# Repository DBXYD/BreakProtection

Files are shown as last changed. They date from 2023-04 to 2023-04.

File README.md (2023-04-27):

# 3A_BREAK

## Components
* MOSFET de puissance, Canal N, 100 V, 31 A, 0.031 ohm, TO-263 (D2PAK), Montage en surface :  
https://fr.farnell.com/nexperia/buk9637-100e-118/mosfet-n-ch-100v-31a-d2pak/dp/2254193

* Régulateur à découpage Buck (Step Down), Fixe, Entrée 7.5V à 76V, Sortie 5V 500mA 125 kHz NSOIC-8 :  
https://fr.farnell.com/maxim-integrated-products/max5033busa/convertisseur-dc-dc-buck-125khz/dp/2513947

* Redresseur Schottky, 100 V, 2 A, Une, DO-220AA, 2 Broche(s), 800 mV :  
https://fr.farnell.com/vishay/ss2ph10-m3-84a/diode-rectifier-schottky-2a-100v/dp/1812489

* WE-PDA SMT Shielded Power Inductor EXTENDED - 784771221 - 220uH 0.99A :  
https://www.we-online.com/catalog/en/WE-PDA?sq=784771221#784771221

* Carte de développement, MCU Nucleo-G431KB, STM32G431KBT6U, Arduino Nano V3 :   
https://fr.farnell.com/stmicroelectronics/nucleo-g431kb/carte-de-dev-32-bits-arm-cortex/dp/3132398

* Bornier fil-à-carte, 5.08 mm, 2 Voies, 26 AWG, 12 AWG, 4 mm², Par vis :  
https://fr.farnell.com/multicomp/mc000034/bornier-ci-noir-5-08mm-vis-02/dp/2008004

* CI Driver de MOSFET, Low Side, Alimentation 4.5V à 16V, 2A Out, 35ns Retard, SOIC-8 :  
https://fr.farnell.com/microchip/tc1412neoa/driver-mosfet-2a-non-inv-8soic/dp/1834898

* Redresseur Schottky, 60 V, 15 A, Une, TO-263AB, 3 Broche(s), 620 mV :  
https://fr.farnell.com/vishay/vs-15tq060s-m3/diode-schottky-simple-60v-to263ab/dp/2909608

* Codeur rotatif, Mécanique, Incrémental, 15 PPR, 30 crans, Verticale, Avec commutateur push :  
https://fr.farnell.com/wurth-elektronik/482016514001/codeur-rotatif-mecanique-incremental/dp/3806131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

* Afficheur LCD, Grove, LCD RGB 16X2 rétroéclairage, Interface I2C :  
https://fr.farnell.com/seeed-studio/104030001/grove-cran-lcd-rvb-r-tro-clair/dp/3932101

## Tools

* Calcul isolement :  
https://www.smps.us/pcbtracespacing.html

## Export Gerber 

CAM Processor
CAMOutputs

### LPKF
* Switch on LPKF
* Open LPKF CircuitPro PM 2.7 software
* Wait few minutes
* Choose Template DoubleSided_Galvanic_THP
* Check Machining -> Connect... (if not) -> S62
* Calibration Key is incorrect -> ok
* Import Data from a non-native format 
* -> Import all gerbers and drillfiles
* Generate isolation and contour -> 35um
* Process -> 4/4

### Photo-ploter
* Gerb2BMP : 
* Import Master Gerber
* Copper_Top // Copper_botton
* Export Gerber to bitmap file (2032 dpi)

* Filmstar : Generate and run on photoploter
* CUIVRE : NEGATIVE !!!
*

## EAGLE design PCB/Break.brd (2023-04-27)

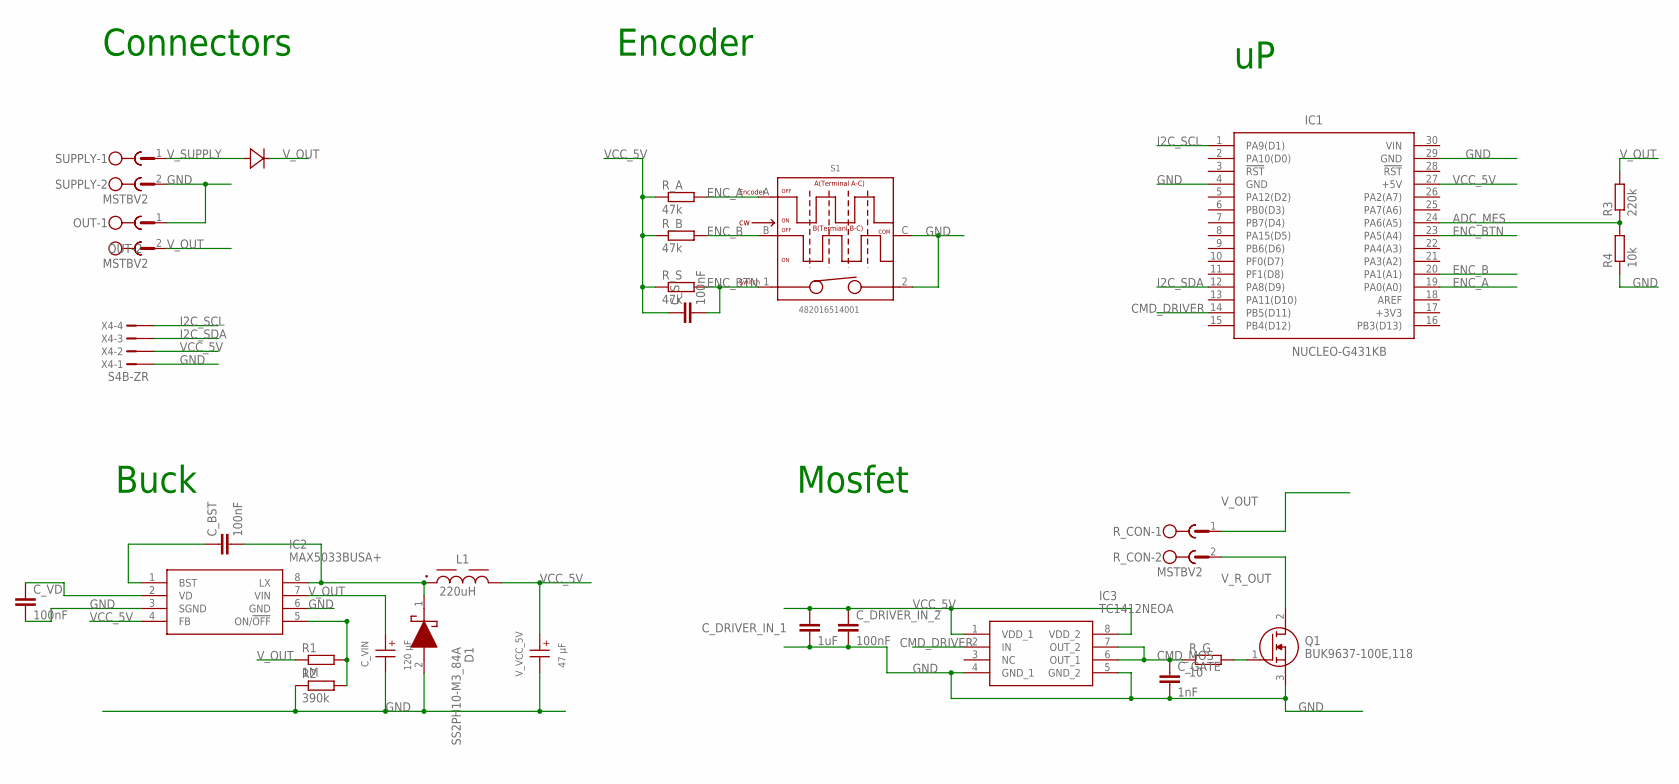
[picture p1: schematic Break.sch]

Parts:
C_BST: 100nF; C0603
C_DRIVER_IN_1: 1uF; C0603
C_DRIVER_IN_2: 100nF; C0603
C_GATE: 1nF; C0603
C_S: 100nF; C0603
C_VD: 100nF; C0603
C_VIN: 120 µF; WCAP-ATG8_18X41X7.5(DXL)
D1: SS2PH10-M3_84A; DO-220AA
IC1: NUCLEO-G431KB; DIPS1524W66P254L5029H1500Q30N
IC2: MAX5033BUSA+; SOIC127P600X175-8N
IC3: TC1412NEOA; SOIC127P600X175-8N
L1: 220uH; WE-PDA_1260
OUT: MSTBV2
Q1: BUK9637-100E,118; PSMN4R480BS118
R1: 1M; R0603
R2: 390k; R0603
R3: 220k; R0603
R4: 10k; R0603
R_A: 47k; R0603
R_B: 47k; R0603
R_CON: MSTBV2
R_G: 10; R1206
R_S: 47k; R0603
S1: 482016514001; WS-ENTV_4820XX514001
SUPPLY: MSTBV2
U$1: VS-15TG060S-M3; SMD-220
V_VCC_5V: 47 µF; WCAP-ASLL_6.3X5.5(DXL)
X4: S4B-ZR

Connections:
ADC_MES: IC1.24 (PA6(A5)), R3.1, R4.2
CMD_DRIVER: IC1.14 (PB5(D11)), IC3.2 (IN)
CMD_MOS: C_GATE.1, IC3.6 (OUT_1), IC3.7 (OUT_2), R_G.1
ENC_A: IC1.19 (PA0(A0)), R_A.2, S1.A
ENC_B: IC1.20 (PA1(A1)), R_B.2, S1.B
ENC_BTN: C_S.2, IC1.23 (PA5(A4)), R_S.2, S1.1
GND: C_DRIVER_IN_1.2, C_DRIVER_IN_2.2, C_GATE.2, C_VD.2, C_VIN.2 (-), D1.2 (A), IC1.4 (GND), IC1.29 (GND), IC2.3 (SGND), IC2.6 (GND), IC3.4 (GND_1), IC3.5 (GND_2), OUT.1, Q1.3 (S), R2.1, R4.1, S1.2, S1.C (COM), SUPPLY.2, V_VCC_5V.2 (-), X4.1
I2C_SCL: IC1.1 (PA9(D1)), X4.4
I2C_SDA: IC1.12 (PA8(D9)), X4.3
unnamed: Q1.1 (G), R_G.2
unnamed: C_BST.2, D1.1 (K), IC2.8 (LX), L1.1
unnamed: C_VD.1, IC2.2 (VD)
unnamed: C_BST.1, IC2.1 (BST)
unnamed: IC2.5 (ON/!OFF), R1.2, R2.2
VCC_5V: C_DRIVER_IN_1.1, C_DRIVER_IN_2.1, C_S.1, IC1.27 (+5V), IC2.4 (FB), IC3.1 (VDD_1), IC3.8 (VDD_2), L1.2, R_A.1, R_B.1, R_S.1, V_VCC_5V.1 (+), X4.2
V_OUT: C_VIN.1 (+), IC2.7 (VIN), OUT.2, R1.1, R3.2, R_CON.1, U$1.P$4 (C)
V_R_OUT: Q1.2 (D), R_CON.2
V_SUPPLY: SUPPLY.1, U$1.P$3 (A)

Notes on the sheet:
Connectors
Buck
Mosfet
Encoder

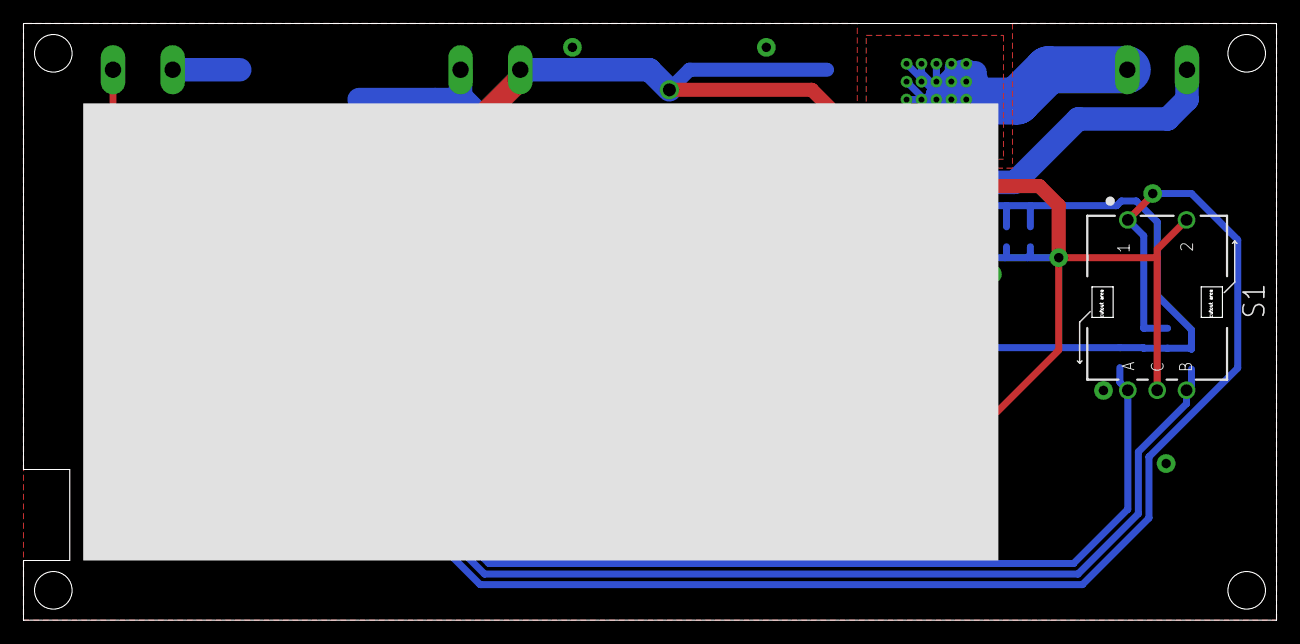
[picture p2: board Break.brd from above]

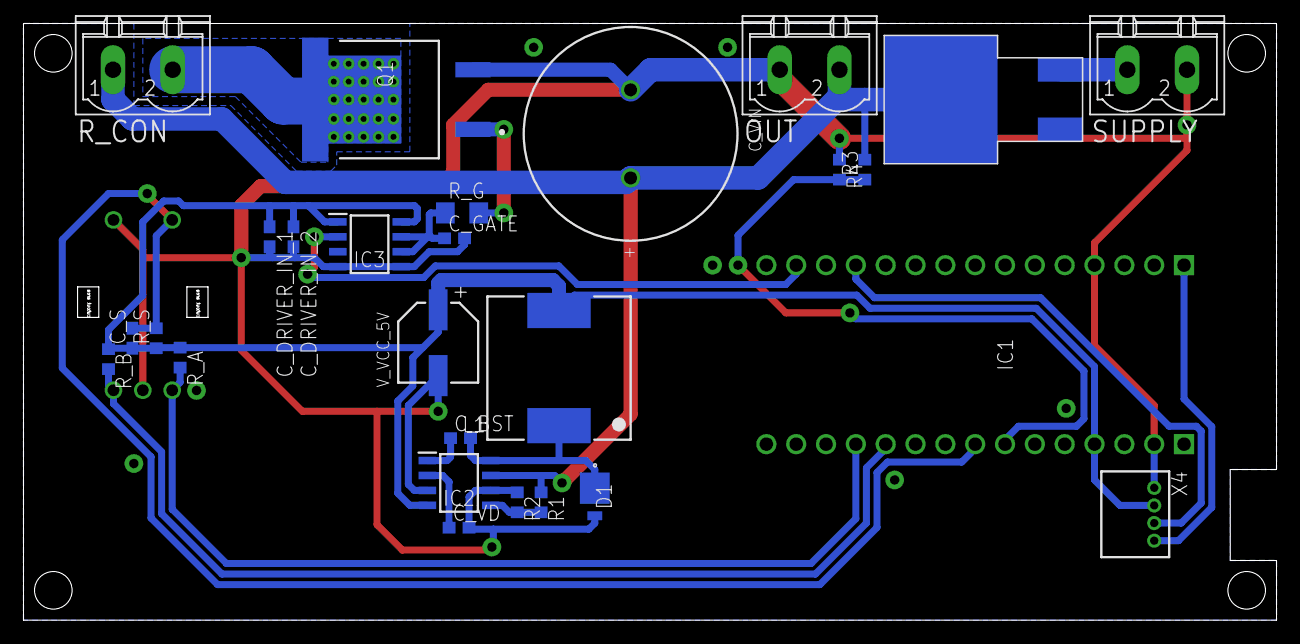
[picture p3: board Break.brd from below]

Board: 2 copper layers, 106.7 x 50.8 mm, 28 parts (27 on the bottom side), 18 nets.

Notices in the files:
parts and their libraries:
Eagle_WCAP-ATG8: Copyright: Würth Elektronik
